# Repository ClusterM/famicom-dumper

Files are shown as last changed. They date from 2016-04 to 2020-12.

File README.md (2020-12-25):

# Famicom Dumper/Writer

WARNING! This project is deprecated. It's highly recommended to use new project: https://github.com/ClusterM/famicom-dumper-writer

## Overview

This is simple dumper/writer for Famicom cartridges.

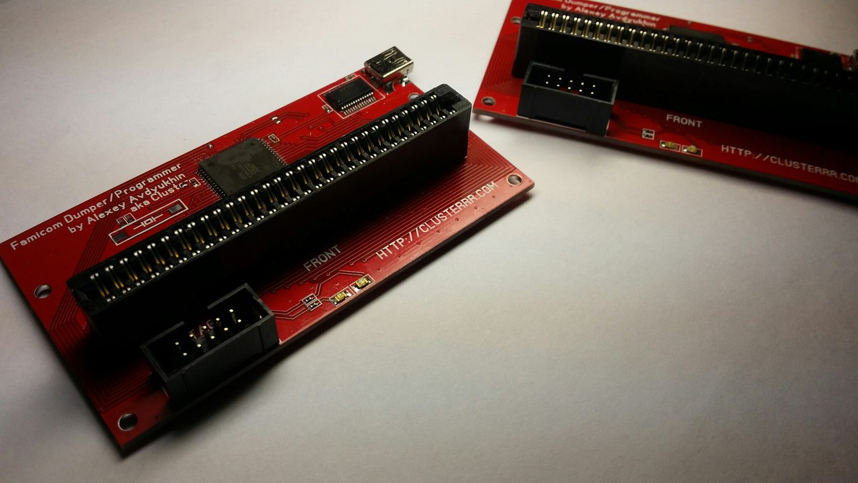
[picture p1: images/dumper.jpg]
Dumper


You can use it to:
* Dump cartridges, so you can play copy of your cartridge on emulator
* Read/write battery backed saves, so you can continue your saved game on emulator/console
* Write special cartridges like [COOLGIRL](https://github.com/ClusterM/coolgirl-famicom-multicard)
* Rewrite ultracheap chinese COOLBOY cartridges. Soldering required but it's very simple.
* Test your cartridges
* Some reverse engineering
* Anything else that requires Famicom bus simulation

## Schematics and parts list

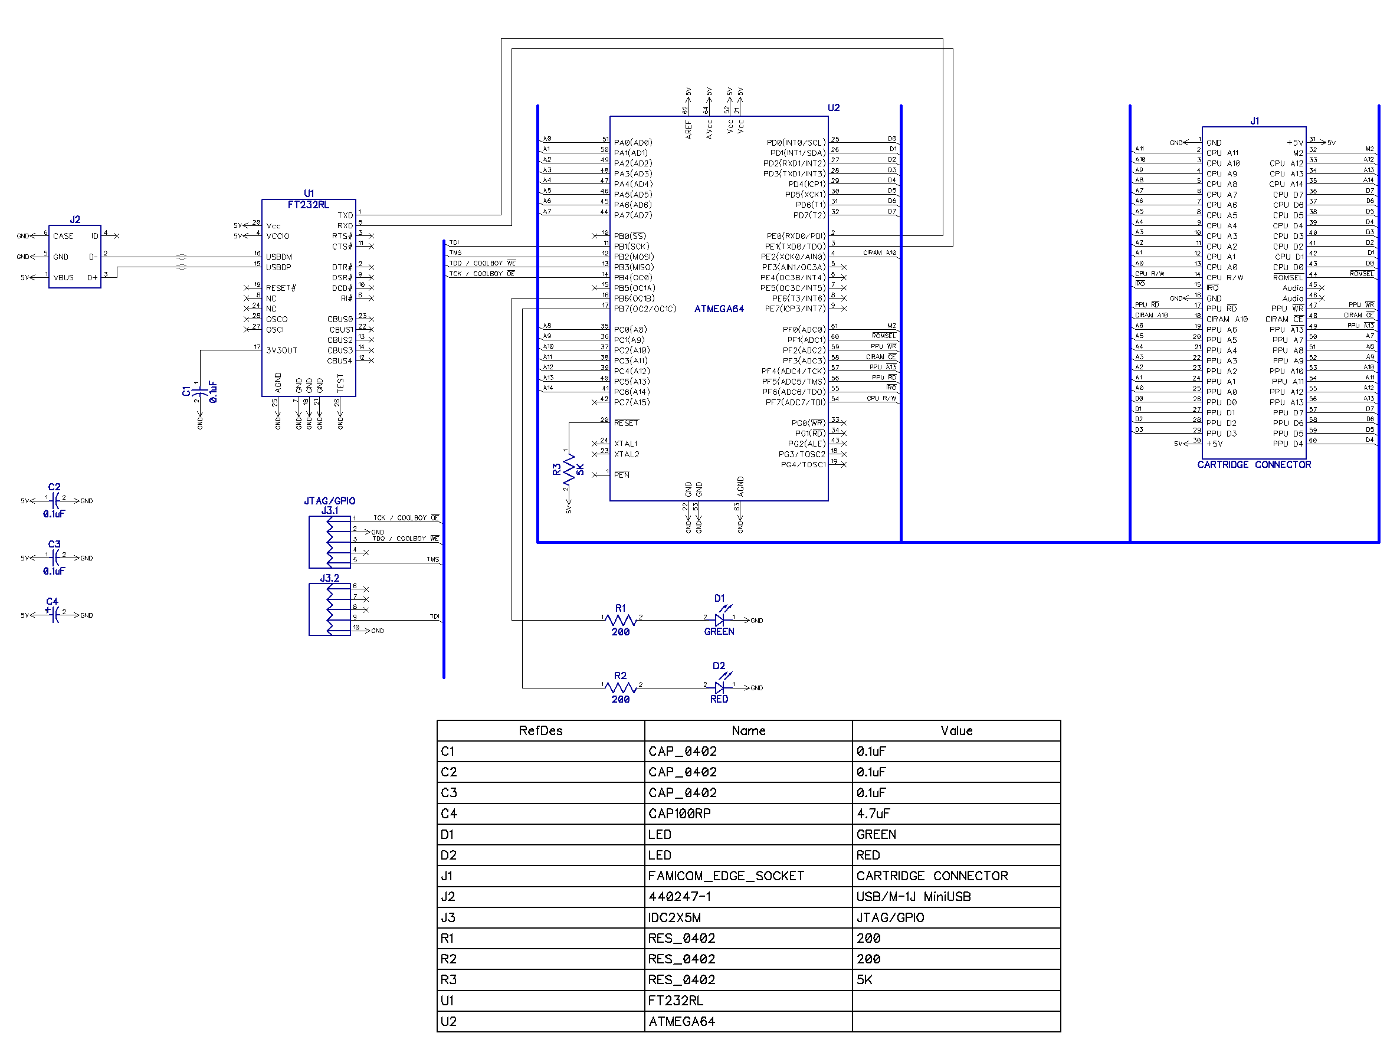
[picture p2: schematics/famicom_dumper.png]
Schematics


You need:
* ATMEGA64
* FT232RL
* 60-pin edge socket
* Printed circuit board, you can order one using files in "board" or "board2" folders.
* Some capacitors
* Maybe some leds

That's all!

## How to compile firmware

All you need is [WinAVR](http://winavr.sourceforge.net/). Just type "make hex" in command line to compile firmware or bootloader.

## How to build it

You need to flash ATMEGA64 microcontroll using any AVR programmer. It's recommended to program bootloader first, so you can flash/update firmware via USB. I'm using bootloader by Martin Thomas, you can use already configured one in bootloader folder. There are fuses for it:
* LFUSE          = E4
* HFUSE          = DC
* EFUSE          = FF

You can program it using command like "**make program PROGRAMMER_TYPE=avrisp2 PROGRAMMER_PORT=usb**" from *bootloader* folder. Don't forget to replace *avrisp2* and *usb* with you programmer type and port.

Connect device to USB and PC will detect it as virtual serial port. First 8 seconds after power up bootloader is active (all leds are on), so you can program main firmware.

You can use command "**make program PROGRAMMER_PORT=COM10**" to program main firmware. Replace *COM10* with port assigned to your dumper (you can use Windows device manager to see it).

Also it's recommended to reprogram FT232 chip using [FT_PROG util](http://www.ftdichip.com/Support/Utilities.htm#FT_PROG) to change device name to "Famicom Dumper/Programmer", so it can be detected automatically by software.

That's all! You can use it now.

## How to use it

Now you need PC-side client to use it: https://github.com/ClusterM/famicom-dumper-client

## How to rewrite COOLBOY cartridges

There are ultracheap chinese COOLBOY cartridges like "400 in 1" or "198 in 1". You can buy them on eBay or Aliexpress. And yes, there is flash memory, so you can rewrite it.

But you need to unsolder pins /OE and /WE and connect them to TCK and TDO pins on JTAG connector:

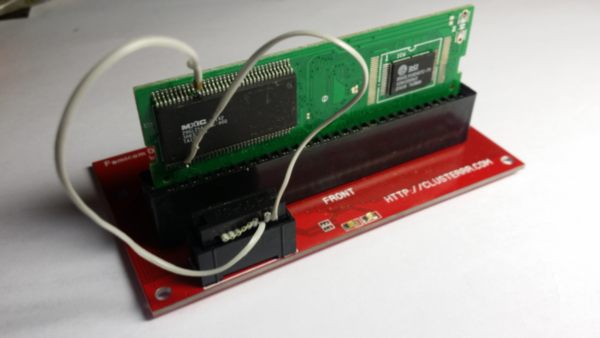
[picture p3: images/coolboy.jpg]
COOLBOY


Don't forget to solder pins back before using cartridge.

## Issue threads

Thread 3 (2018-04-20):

EDA files, and question

BRFud, 2018-04-20:
Hi,

I very new to nes development / cart dumping and I had a few questions about this project:

1. Are the EDA files available for this project(Kicad or Eagle, etc)? As I am thinking I may want to edit the components slightly and re-arrange the PCB.
2. What are the main differences/advantages/limitations between this project and Kazzo or other NES/famicom cart programmers/dumpers?

Thanks for your time and your work on this and other projects.

mindstation, 2018-04-22:
There are the EDA files in the project.
It's a "board/famicom_dumper.lay6" for the first version board. The file was created under Sprint Layout.
The "board2/famicom_dumper.dip" and schematic "schematics/famicom_dumper.dch" was created under DipTrace (it's free for small circuit boards).

I did not use any other NES/Famicom dumpers and can't answer other question. Maybe the author can.

Closed 2018-09-03.

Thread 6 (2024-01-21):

Ошибка чтения CHR памяти.

sapbotgit, 2024-01-21:
Сама prg память сдампилась хорошо, а вот с chr проблемы.

https://github.com/ClusterM/famicom-dumper/assets/120243584/4ce941e2-0e7b-4fc5-95e8-58fb1e3d441e

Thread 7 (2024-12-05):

Voltage for the SPI programming logic?

Roet-Ivar, 2024-12-05:
Nice project. I just picked up this legacy version for cheap and I it apparently came without any programming.
What voltage should my SPI programmer use for the bootloader?

Roet-Ivar, 2024-12-11:
oh maybe I'm mistaken on how to connect it. Would you like to expand, maybe with a picture or two?
I've been trying to upload the bootloader main.hex from an esp32-adruino-spi programmer to these pins:
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

pavelkokorin, 2024-12-11:
@Roet-Ivar, i have sort of proto-board, so my pictures will not be relevant, sorry.
I check your pcb layout, and it seems to be correct: mosi goes to pin2, miso to pin3, sck to pin11 and reset to pin20.

> When you say "bootloader approach", I thought a bootloader was a prerequisite for it work at all?

"It's recommended to program bootloader first, so you can flash/update firmware via USB." So, it's a recommendation from the author. You can flash a firmware directly using avr programmer without bootloader. Precompiled firmware is already in the repo https://github.com/ClusterM/famicom-dumper/blob/master/famicom-dumper.hex
So it's on your choice which way to use. I chose program with programmer without bootloader.

>I've been trying to upload the bootloader main.hex from an esp32-arduino-spi programmer (which I've successfully used before) to these pins, but it might be using 3.3V logic for programming

What result did you get?

1. where vpp comes from? do you use USB to power it up?
2. please check that clock source has set correctly in fuses, if you use not brand new mcu, maybe it expects external crystal to work. i have had exactly that situation. Correct fuses value: LFUSE = E4, HFUSE = DC, EFUSE = FF
3. i tried to use 3.3v VPP from isp programmer, but the result in my case was unstable, there were validation errors. so i switch to 5v VPP. USBasp Programmer has that switch.

Roet-Ivar, 2024-12-11:
@pavelkokorin First, thank you very much for the elaborate reply!
"It's recommended to program bootloader first, so you can flash/update firmware via USB."
Ok, so skipping the bootloader would leave out the possibility of letting the onboard programmer to be used, gotha!

OT: I have a little sidequest that I'd like to explore using this device, namely dumping the cartridge rom directly to an SD-card when started. If you would have any ideas of an approach to this I'm all ears. Anyway thank very much for clarifying.

pavelkokorin, 2024-12-12:
> OT: I have a little sidequest that I'd like to explore using this device, namely dumping the cartridge rom directly to an SD-card when started. If you would have any ideas of an approach to this I'm all ears.

@Roet-Ivar, this dumper requires PC to make cartridge dumps, cause it has no knowledge on how to deal with tons of nes mappers. The entire logic contains in c# scripts on the client side (https://github.com/ClusterM/famicom-dumper-client). It's more likely aimed to reverse engineering and researching.

If you want to save dumps directly to SD card on MCU side, you have to migrate those mapper logic to MCU side as well. There is another similar project https://github.com/sanni/cartreader/, which at glance is closer to your requirements.

Roet-Ivar, 2024-12-12:
@pavelkokorin Oh crap, you're right! Thanks

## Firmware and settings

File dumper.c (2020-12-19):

/* Famicom Dumper/Programmer
 *
 * Copyright notice for this file:
 *  Copyright (C) 2020 Cluster
 *  http://clusterrr.com
 *  clusterrr@clusterrr.com
 *
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
 */

#include "defines.h"
#include <avr/io.h>
#include <avr/interrupt.h>
#include <avr/wdt.h>
#include <util/delay.h>
#include <inttypes.h>
#include "usart.h"
#include "comm.h"
#include "dumper.h"
#include "crc.h"

static void (*jump_to_bootloader)(void) = (void*)0xF800;
uint16_t flash_buffer_mask = 0xFFC0;

ISR(USART0_RX_vect)
{
  unsigned char b;
  while (UCSR0A & (1<<RXC0))
  {
    b = UDR0;
    comm_proceed(b);
  }
}

static void set_flash_buffer_size(uint16_t value)
{
  // Set maximum number of bytes in multi-byte program
  uint8_t bit_value = 0;
  while (value > 1)
  {
    value >>= 1;
    bit_value++;
  }
  flash_buffer_mask = 0xFFFF << bit_value;
}

static void set_address(uint16_t address)
{
  unsigned char l = address & 0xFF;
  unsigned char h = (address >> 8) & 0xFF;
  
  PORTA = l;
  PORTC = h;
  
  // PPU /A13
  if ((address >> 13) & 1)
    PORTF &= ~(1<<4);
  else
    PORTF |= 1<<4;
}

static inline void set_romsel(uint16_t address)
{
  if (address & 0x8000)
  {
    ROMSEL_LOW;
  } else {
    ROMSEL_HI;
  }
}

static inline void set_coolboy_rd(uint16_t address)
{
  if (address & 0x8000)
  {
    COOLBOY_PORT |= 1<<COOLBOY_WR_PIN;
    COOLBOY_PORT &= ~(1<<COOLBOY_RD_PIN);
  } else {
    COOLBOY_PORT |= 1<<COOLBOY_WR_PIN;
    COOLBOY_PORT |= 1<<COOLBOY_RD_PIN;
  }
}

static inline void set_coolboy_wr(uint16_t address)
{
  if (address & 0x8000)
  {
    COOLBOY_PORT &= ~(1<<COOLBOY_WR_PIN);
    COOLBOY_PORT |= 1<<COOLBOY_RD_PIN;
  } else {
    COOLBOY_PORT |= 1<<COOLBOY_WR_PIN;
    COOLBOY_PORT |= 1<<COOLBOY_RD_PIN;
  }
}

static unsigned char read_prg_byte(uint16_t address)
{
  PHI2_LOW;
  ROMSEL_HI;
  MODE_READ;
  PRG_READ;  
  set_address(address);
  PHI2_HI;
  set_romsel(address); // set /ROMSEL low if need
  set_coolboy_rd(address); // COOLBOY's /oe low if need
  _delay_us(1);
  uint8_t result = PIND;
  ROMSEL_HI;
  set_coolboy_rd(0);
  return result;
}

static unsigned char read_chr_byte(uint16_t address)
{
  PHI2_LOW;
  ROMSEL_HI;
  MODE_READ;
  set_address(address);
  CHR_READ_LOW;
  _delay_us(1);
  uint8_t result = PIND;
  CHR_READ_HI;
  PHI2_HI;
  return result;
}

static void read_prg_send(uint16_t address, uint16_t len)
{
  LED_GREEN_ON;
  comm_start(COMMAND_PRG_READ_RESULT, len);
  while (len > 0)
  {
    comm_send_byte(read_prg_byte(address));
    len--;
    address++;
  }
  set_address(0);
  LED_GREEN_OFF;
}

static void read_chr_send(uint16_t address, uint16_t len)
{
  LED_GREEN_ON;
  comm_start(COMMAND_CHR_READ_RESULT, len);
  while (len > 0)
  {
    comm_send_byte(read_chr_byte(address));
    len--;
    address++;
  }
  set_address(0);
  LED_GREEN_OFF;
}

static void read_prg_crc_send(uint16_t address, uint16_t len)
{
  LED_GREEN_ON;
  uint16_t crc = 0;
  MODE_READ;
  PRG_READ;  
  PHI2_HI;
  set_romsel(address); // set /ROMSEL low if need
  while (len > 0)
  {
    PORTA = address & 0xFF;
    PORTC = (address >> 8) & 0xFF;
    _delay_us(1);
    crc = calc_crc16(crc, PIND);
    len--;
    address++;
  }
  ROMSEL_HI;
  set_address(0);
  comm_start(COMMAND_PRG_READ_RESULT, 2);
  comm_send_byte(crc & 0xFF);
  comm_send_byte((crc >> 8) & 0xFF);
  LED_GREEN_OFF;
}

static void read_chr_crc_send(uint16_t address, uint16_t len)
{
  LED_GREEN_ON;
  uint16_t crc = 0;
  while (len > 0)
  {
    crc = calc_crc16(crc, read_chr_byte(address));
    len--;
    address++;
  }
  set_address(0);
  comm_start(COMMAND_CHR_READ_RESULT, 2);
  comm_send_byte(crc & 0xFF);
  comm_send_byte((crc >> 8) & 0xFF);
  LED_GREEN_OFF;
}

static void write_prg_byte(uint16_t address, uint8_t data)
{
  PHI2_LOW;
  ROMSEL_HI;
  MODE_WRITE;
  PRG_WRITE;
  PORTD = data;
  set_address(address); // PHI2 low, ROMSEL always HIGH
  _delay_us(1);
  
  PHI2_HI;
  set_romsel(address); // ROMSEL is low if need, PHI2 high  
  set_coolboy_wr(address); // COOLBOY's /we is low if need
  
  _delay_us(1); // WRITING
  
  // PHI2 low, ROMSEL high
  PHI2_LOW;
  ROMSEL_HI;
  set_coolboy_wr(0);
  
  // Back to read mode
  _delay_us(1);
  PRG_READ;
  MODE_READ;
  set_address(0);

  // Set phi2 to high state to keep cartridge unreseted
  PHI2_HI;
}

static void write_chr_byte(uint16_t address, uint8_t data)
{
  PHI2_LOW;
  ROMSEL_HI;
  MODE_WRITE;
  PORTD = data;  
  set_address(address); // PHI2 low, ROMSEL always HIGH
  CHR_WRITE_LOW;
    
  _delay_us(1); // WRITING
  
  CHR_WRITE_HI;
  
  MODE_READ;
  set_address(0);
  PHI2_HI;
}

static void write_prg(uint16_t address, uint16_t len, uint8_t* data)
{
  LED_RED_ON;
  while (len > 0)
  {
    write_prg_byte(address, *data);
    address++;
    len--;
    data++;
  }
  LED_RED_OFF;
}

static void write_chr(uint16_t address, uint16_t len, uint8_t* data)
{
  LED_RED_ON;
  while (len > 0)
  {
    write_chr_byte(address, *data);
    address++;
    len--;
    data++;
  }
  LED_RED_OFF;
}

static inline void write_prg_flash_command(uint16_t address, uint8_t data)
{
  write_prg_byte(address | 0x8000, data);
}

static void erase_flash_sector()
{
  LED_RED_ON;
  write_prg_flash_command(0x0000, 0xF0);
  write_prg_flash_command(0x0AAA, 0xAA);
  write_prg_flash_command(0x0555, 0x55);
  write_prg_flash_command(0x0AAA, 0x80);
  write_prg_flash_command(0x0AAA, 0xAA);
  write_prg_flash_command(0x0555, 0x55);
  write_prg_flash_command(0x0000, 0x30);
  
  uint8_t res;
  int16_t last_res = -1;
  TCNT1 = 0;
  // waiting for result
  while (1)
  {
    if (TCNT1 >= 23437) // 3 seconds
    {
      // timeout
      comm_start(COMMAND_FLASH_ERASE_TIMEOUT, 0);
      break;
    }
    res = read_prg_byte(0x8000);
    if ((last_res == -1) || ((res != (last_res & 0xFF))))
    {
      // in progress
      last_res = res;
      continue;
    }
    // done
    if (res == 0xFF)
    {
       // ok
       comm_start(COMMAND_PRG_WRITE_DONE, 0);
       break;
    } else {
       // error
       comm_start(COMMAND_FLASH_ERASE_ERROR, 1);
       comm_send_byte(res);
       break;
    }
  }
  LED_RED_OFF;
}

static void write_flash(uint16_t address, uint16_t len, uint8_t* data)
{
  LED_RED_ON;
  while (len > 0)
  {
    uint16_t count = 0;
    uint8_t* d = data;
    uint16_t a = address;
    uint16_t last_address;
    uint8_t last_data;
    uint16_t address_base = a & flash_buffer_mask;
    while ((len > 0) && ((a & flash_buffer_mask) == address_base))
    {
      if (*d != 0xFF)
        count++;
      a++;
      len--;
      d++;
    }

    if (count)
    {
      write_prg_flash_command(0x0000, 0xF0);
      write_prg_flash_command(0x0AAA, 0xAA);
      write_prg_flash_command(0x0555, 0x55);
      write_prg_flash_command(0x0000, 0x25);
      write_prg_flash_command(0x0000, count-1);

      while (count > 0)
      {
        if (*data != 0xFF)
        {
          write_prg_flash_command(address, *data);
          last_address = address;
          last_data = *data;
          count--;
        }
        address++;
        data++;
      }
    
      write_prg_flash_command(0x0000, 0x29);

      TCNT1 = 0;
      // waiting for result
      while (1)
      {
        if (TCNT1 >= 7812) // 1 second
        {
          // timeout
          comm_start(COMMAND_FLASH_WRITE_TIMEOUT, 0);
          LED_RED_OFF;
          return;
        }
        uint8_t read_1 = read_prg_byte(last_address | 0x8000);
        uint8_t read_2 = read_prg_byte(last_address | 0x8000);
        uint8_t read_3 = read_prg_byte(last_address | 0x8000);
        if (((read_1 ^ read_2) & (1 << 6)) && ((read_2 ^ read_3) & (1 << 6)))
        {
          if (read_1 & (1 << 1))
          {
            comm_start(COMMAND_FLASH_WRITE_ERROR, 3);
            comm_send_byte(read_1);
            comm_send_byte(read_2);
            comm_send_byte(read_3);
            LED_RED_OFF;
            return;
          } else if (read_1 & (1 << 5)) {
            comm_start(COMMAND_FLASH_WRITE_TIMEOUT, 3);
            comm_send_byte(read_1);
            comm_send_byte(read_2);
            comm_send_byte(read_3);
            LED_RED_OFF;
            return;
          }
        } else {
          read_1 = read_prg_byte(last_address | 0x8000);
          read_2 = read_prg_byte(last_address | 0x8000);
          if (read_1 == read_2 && read_2 == last_data)
            break; // ok
        }
      }
    }

    address = a;
    data = d;
  }
  comm_start(COMMAND_PRG_WRITE_DONE, 0);
  LED_RED_OFF;
}

static uint8_t transfer_fds_byte(uint8_t *output, uint8_t input, uint8_t *end_of_head)
{
  TCNT1 = 0;
  while (!IRQ_FIRED)
  {
    // waiting for interrupt
    // timeout 5 secs
    if (TCNT1 >= 39060)
    {
      write_prg_byte(FDS_CONTROL, FDS_CONTROL_READ | FDS_MOTOR_OFF); // reset, stop
      comm_start(COMMAND_FDS_TIMEOUT, 0);
      return 0;
    }
  }
  if (output)
    *output = read_prg_byte(FDS_DATA_READ);
  write_prg_byte(FDS_DATA_WRITE, input); // clear interrupt
  uint8_t status = read_prg_byte(FDS_DISK_STATUS);
  if (end_of_head)
    *end_of_head |= (status >> 6) & 1;
  TCNT1 = 0;
  while (IRQ_FIRED)
  {
    // is interrupt flag cleared?
    // timeout 5 secs
    if (TCNT1 >= 39060)
    {
      write_prg_byte(FDS_CONTROL, FDS_CONTROL_READ | FDS_MOTOR_OFF); // reset, stop
      comm_start(COMMAND_FDS_TIMEOUT, 0);
      return 0;
    }
  }
  return 1;
}

static uint8_t read_fds_block_send(uint16_t length, uint8_t send, uint8_t *crc_ok, uint8_t *end_of_head, uint16_t *file_size, uint32_t gap_delay)
{
  uint8_t data;
  uint8_t status;
  uint32_t b;

  write_prg_byte(FDS_CONTROL, FDS_CONTROL_READ | FDS_CONTROL_MOTOR_ON); // motor on without transfer
  if (gap_delay < 30000)
    DELAY_CLOCK(gap_delay);
  else
    DELAY_KILO_CLOCK(gap_delay / 1000);
  if (send)
  {
    LED_GREEN_ON;
    comm_start(COMMAND_FDS_READ_RESULT_BLOCK, length + 2);
  }
  // start transfer, enable IRQ
  write_prg_byte(FDS_CONTROL, FDS_CONTROL_READ | FDS_CONTROL_MOTOR_ON | FDS_CONTROL_TRANSFER_ON | FDS_CONTROL_IRQ_ON);
  for (b = 0; b < length; b++)
  {
    if (!transfer_fds_byte(&data, 0, end_of_head))
      return 0;
    if (file_size)
    {
      if (b == 13)
        *file_size |= data;
      else if (b == 14)
        *file_size |= data << 8;
    }
    if (send)
      comm_send_byte(data);
  }
  if (!transfer_fds_byte(0, 0, end_of_head))
    return 0;
  write_prg_byte(FDS_CONTROL, FDS_CONTROL_READ | FDS_CONTROL_MOTOR_ON | FDS_CONTROL_TRANSFER_ON | FDS_CONTROL_IRQ_ON | FDS_CONTROL_CRC); // enable CRC control
  if (!transfer_fds_byte(0, 0, end_of_head))
    return 0;
  status = read_prg_byte(FDS_DISK_STATUS);
  *crc_ok &= ((status >> 4) & 1) ^ 1;
  *end_of_head |= (status >> 6) & 1;
  if (send)
  {
    comm_send_byte(*crc_ok); // CRC check result
    comm_send_byte(*end_of_head); // end of head meet?
  }
  LED_GREEN_OFF;
  return 1; // success
}

static uint8_t write_fds_block(uint8_t *data, uint16_t length, uint32_t gap_delay)
{
  uint8_t end_of_head = 0;
  LED_RED_ON;
  write_prg_byte(FDS_CONTROL, FDS_CONTROL_READ | FDS_CONTROL_MOTOR_ON); // motor on without transfer
  read_prg_byte(FDS_DRIVE_STATUS); // check if disk is inserted
  write_prg_byte(FDS_CONTROL, FDS_CONTROL_WRITE | FDS_CONTROL_MOTOR_ON); // enable writing without transfer
  if (gap_delay < 30000)
    DELAY_CLOCK(gap_delay);
  else
    DELAY_KILO_CLOCK(gap_delay / 1000);
  write_prg_byte(FDS_DATA_WRITE, 0x00); // write $00
  // start transfer, enable IRQ
  write_prg_byte(FDS_CONTROL, FDS_CONTROL_WRITE | FDS_CONTROL_MOTOR_ON | FDS_CONTROL_TRANSFER_ON | FDS_CONTROL_IRQ_ON);
  transfer_fds_byte(0, 0x80, &end_of_head);  // write $80
  while (length)
  {
    if (end_of_head)
    {
      write_prg_byte(FDS_CONTROL, FDS_CONTROL_READ | FDS_MOTOR_OFF); // reset, stop
      comm_start(COMMAND_FDS_END_OF_HEAD, 0);
      return 0;
    }
    if (!transfer_fds_byte(0, *data, &end_of_head))
    {
      write_prg_byte(FDS_CONTROL, FDS_CONTROL_READ | FDS_MOTOR_OFF); // reset, stop
      comm_start(COMMAND_FDS_TIMEOUT, 0);
      return 0;
    }
    data++;
    length--;
  }
  if (!transfer_fds_byte(0, 0xFF, &end_of_head))
  {
    write_prg_byte(FDS_CONTROL, FDS_CONTROL_READ | FDS_MOTOR_OFF); // reset, stop
    comm_start(COMMAND_FDS_TIMEOUT, 0);
    return 0;
  }
  if (end_of_head)
  {
    write_prg_byte(FDS_CONTROL, FDS_CONTROL_READ | FDS_MOTOR_OFF); // reset, stop
    comm_start(COMMAND_FDS_END_OF_HEAD, 0);
    return 0;
  }
  write_prg_byte(FDS_CONTROL, FDS_CONTROL_WRITE | FDS_CONTROL_MOTOR_ON | FDS_CONTROL_TRANSFER_ON | FDS_CONTROL_IRQ_ON | FDS_CONTROL_CRC);  // enable CRC control
  DELAY_CLOCK(FDS_WRITE_CRC_DELAY);
  TCNT1 = 0;
  while (1)
  {
    uint8_t status = read_prg_byte(FDS_DRIVE_STATUS);
    if (!(status & 2))
      break; // ready
    // timeout 1 sec
    if (TCNT1 >= 7812)
    {
      write_prg_byte(FDS_CONTROL, FDS_CONTROL_READ | FDS_MOTOR_OFF); // reset, stop
      comm_start(COMMAND_FDS_TIMEOUT, 0);
      return 0;
    }
  }  
  LED_RED_OFF;
  return 1;
}
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
int main (void)
{
  sei();
  USART_init();
  init_ports();

  LED_RED_OFF;
  LED_GREEN_OFF;  
  
  comm_init();
  comm_start(COMMAND_PRG_STARTED, 0);

  uint32_t address;
  uint32_t length;
  
  unsigned long int t = 0;
  char led_down = 0;
  int led_bright = 0;
  
  while (1)
  {
    // PWM for leds
    TCCR1A |= (1<<COM1C1) | (1<<COM1B1) | (1<<WGM10);
    TCCR1B = 1<<CS10; // no prescaler
    if (t++ >= 10000)
    {
      if (!led_down)
      {
        led_bright++;
        if (led_bright >= 110) led_down = 1;
      } else {
        led_bright--;
        if (!led_bright) led_down = 0;
      }
      if (led_bright >= 100) OCR1B = led_bright - 100;
      if (led_down)
      {
        int led_bright2 = 110-led_bright;
        if (led_bright2 <= 20)
        {
          if (led_bright2 > 10) led_bright2 = 20 - led_bright2;
          OCR1C = led_bright2*2;
        }
      }
      t = 0;
    }
    
    if (comm_recv_done)
    {
      comm_recv_done = 0;
      t = led_down = led_bright = 0;
      // Just timer without PWM for timeouts
      TCCR1A = OCR1B = OCR1C = 0;
      TCCR1B = (1<<CS12) | (1<<CS10); // /1024 prescaler
      
      switch (comm_recv_command)
      {
        case COMMAND_PRG_INIT:
          comm_start(COMMAND_PRG_STARTED, 5);
          comm_send_byte(PROTOCOL_VERSION);
          comm_send_byte((SEND_BUFFER_SIZE - 5) & 0xFF);
          comm_send_byte(((SEND_BUFFER_SIZE - 5) >> 8) & 0xFF);
          comm_send_byte((RECV_BUFFER_SIZE - 5) & 0xFF);
          comm_send_byte(((RECV_BUFFER_SIZE - 5) >> 8) & 0xFF);
          break;
          
        case COMMAND_COOLBOY_READ_REQUEST:
        case COMMAND_PRG_READ_REQUEST:
          address = recv_buffer[0] | ((uint16_t)recv_buffer[1]<<8);
          length = recv_buffer[2] | ((uint16_t)recv_buffer[3]<<8);
          read_prg_send(address, length);
          break;

        case COMMAND_PRG_CRC_READ_REQUEST:
          address = recv_buffer[0] | ((uint16_t)recv_buffer[1]<<8);
          length = recv_buffer[2] | ((uint16_t)recv_buffer[3]<<8);
          read_prg_crc_send(address, length);
          break;

        case COMMAND_PRG_WRITE_REQUEST:
          address = recv_buffer[0] | ((uint16_t)recv_buffer[1]<<8);
          length = recv_buffer[2] | ((uint16_t)recv_buffer[3]<<8);
          write_prg(address, length, (uint8_t*)&recv_buffer[4]);
          comm_start(COMMAND_PRG_WRITE_DONE, 0);
          break;

        case COMMAND_RESET:
          reset_phi2();
          comm_start(COMMAND_RESET_ACK, 0);
          break;
          
        case COMMAND_FLASH_ERASE_SECTOR_REQUEST:
        case COMMAND_COOLBOY_ERASE_SECTOR_REQUEST:
          erase_flash_sector();
          break;

        case COMMAND_FLASH_WRITE_REQUEST:
        case COMMAND_COOLBOY_WRITE_REQUEST:
          address = recv_buffer[0] | ((uint16_t)recv_buffer[1]<<8);
          length = recv_buffer[2] | ((uint16_t)recv_buffer[3]<<8);
          write_flash(address, length, (uint8_t*)&recv_buffer[4]);
          break;
          
        case COMMAND_CHR_INIT:
          comm_start(COMMAND_CHR_STARTED, 0);
          break;
          
        case COMMAND_CHR_READ_REQUEST:
          address = recv_buffer[0] | ((uint16_t)recv_buffer[1]<<8);
          length = recv_buffer[2] | ((uint16_t)recv_buffer[3]<<8);
          read_chr_send(address, length);
          break;

        case COMMAND_CHR_CRC_READ_REQUEST:
          address = recv_buffer[0] | ((uint16_t)recv_buffer[1]<<8);
          length = recv_buffer[2] | ((uint16_t)recv_buffer[3]<<8);
          read_chr_crc_send(address, length);
          break;

        case COMMAND_CHR_WRITE_REQUEST:
          address = recv_buffer[0] | ((uint16_t)recv_buffer[1]<<8);
          length = recv_buffer[2] | ((uint16_t)recv_buffer[3]<<8);
          write_chr(address, length, (uint8_t*)&recv_buffer[4]);
          comm_start(COMMAND_CHR_WRITE_DONE, 0);
          break;

        case COMMAND_FDS_READ_REQUEST:
          fds_transfer(recv_buffer[0], recv_buffer[1], 0, 0, 0, 0);
          break;

        case COMMAND_FDS_WRITE_REQUEST:
          fds_transfer(0, 0, recv_buffer[0], (uint8_t*) &recv_buffer[1], (uint16_t*) &recv_buffer[1 + recv_buffer[0]],
            (uint8_t*) &recv_buffer[1 + recv_buffer[0] + recv_buffer[0] * 2]);
          break;        
        
        case COMMAND_MIRRORING_REQUEST:
          get_mirroring();
          break;
          
        case COMMAND_SET_FLASH_BUFFER_SIZE:
          set_flash_buffer_size(recv_buffer[0] | ((uint16_t) recv_buffer[1] << 8));
          comm_start(COMMAND_SET_VALUE_DONE, 0);
          break;

        case COMMAND_BOOTLOADER:
          cli();
          MCUCSR = 0;
          jump_to_bootloader();
      }

      LED_GREEN_OFF;
      LED_RED_OFF;
    }    
  }
}

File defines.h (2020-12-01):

#ifndef _DEFINES_H_
#define _DEFINES_H_

#define F_CPU 8000000UL
#define UART_BAUD 250000UL
#define RECV_BUFFER_SIZE 2048
#define SEND_BUFFER_SIZE 2048
#define PROTOCOL_VERSION 3

#define COOLBOY_GPIO_PORT B
#define COOLBOY_RD_PIN 4
#define COOLBOY_WR_PIN 3

#endif

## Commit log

2016-04-18 Schematics fix
2016-04-18 New schematics, alternative board
    [Board.gbr, BoardOutline.gbr, Bottom.gbr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]
2016-04-18 Docs and some fixes
    [TopSilk.gbr]
2016-10-20 Board fixes
    [Board.gbr, Bottom.gbr, Through.drl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]
2017-08-09 Устранил прямые углы на дорожках. Поправил часть зазоров между дорожками и пинами. Переместил несколько переходных отверстий чтобы поправить заливку.
2017-08-20 CRC calculation
    [BoardOutline.gbr, Bottom.gbr, BottomMask.gbr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]
2017-08-24 Changed 1-440247-1 to 440247-1 (with holes).
2017-08-25 Scheme Changed USB connector to 440247-1. PCB Retraced USB Data+ and USB Data-.
2017-09-09 Edit famicom_dumper.dip Retrace USB for new connector. Edit some traces and via pads.
2017-09-25 Update schematic Change USB data net type to differencial. Update BOM table.
2017-09-26 Update schematic net classes.
2017-09-26 Update PCB. Make differencial USB trace. Move alloy to silk layer. Set Rezonit DRC rules.
2017-09-26 Update scheme and PCB diff net style. For flawless DRC checking. Check and correcting PCB for rezonit rules.
2017-09-28 Update PCB. Add more information to top and bottom silk. Few via editing.
2017-09-29 Update PCB. Edit cartridge connector silk.
2017-10-01 Update PCB. Regroup famicom connector as component.
2017-10-01 Update PCB. Grouping components with they tip text.
2017-10-01 Update PCB. Move vias away from silk. Edit traces for beauty.
2017-10-03 Update PCB. Edit bottom trace for clean copper pour. Update copper pour.
2017-10-04 Update PCB. Make silk fit rezonit requirements. Widht line min 0,2 mm.
2017-11-23 A new board2 was exported for production.
    [BoardOutline.gbr, Bottom.gbr, BottomMask.gbr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]
2020-07-15 Fix in PRG read operation
    [dumper.c]
2020-09-02 More correct flash write check
    [comm.h, dumper.c]
2020-09-05 Using hardware timer for timeouts
2020-10-12 More correct flash write check, refactoring
    [dumper.c]
2020-10-13 Fixed page programming size (64, no 32)
    [dumper.c]
2020-10-17 Readme: fixed typo
    it → in
2020-12-01 Timer fix
2020-12-02 FDS battery check
2020-12-19 256-byte multibyte program fix
    [dumper.c]
